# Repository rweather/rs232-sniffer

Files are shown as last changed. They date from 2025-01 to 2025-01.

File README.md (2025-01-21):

RS-232 Sniffer Box
==================

This repository contains schematics, a PCB layout, and 3D-printable box
for a "RS-232 Sniffer" that my friend Chris asked me to design in 2019.

Chris needed a way to sniff the traffic between two serial devices,
and to get a visual indication as to which signals were active.

A little bit of mucking around in [KiCad](https://www.kicad.org/) and
[OpenSCAD](https://openscad.org/) and I had a design.  Chris later
improved on my original 3D-printable box design.

Multiple copies of the box have been made and have seen heavy use at
our workplace for monitoring serial communications; particularly for
SCADA systems.

The boxes have also proven useful to check if serial ports are working
at all, and to track down problems with RTS/CTS handshaking and the like.

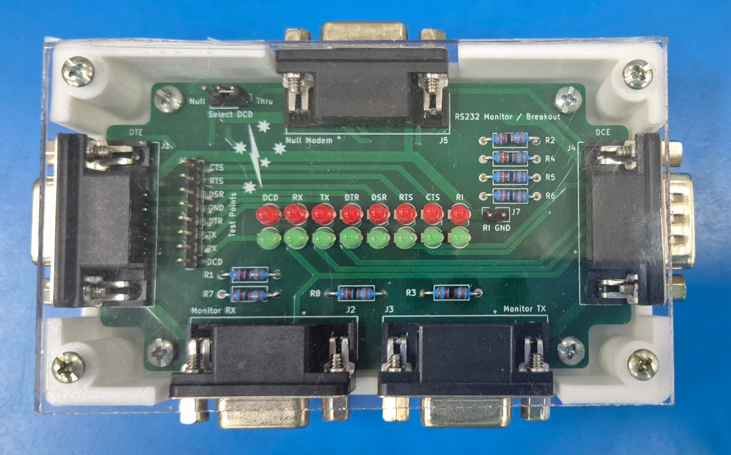
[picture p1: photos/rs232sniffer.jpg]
RS-232 Sniffer Box


## Capabilities

* Pass-through from one end of the box to the other for the main
serial communications path.
* Two extra serial ports for monitoring the RX and TX sides of the
communications.  Any bytes that are sent on that side are also sent
to the "sniffer" ports, for monitoring on a connected PC using a
terminal program like [PuTTY](https://www.putty.org/).
* Optional null modem connection to cross-over RX and TX.
* Red and green LED's to indicate which RS-232 lines have a high or
low signal on them.
* Probe points to monitor the RS-232 signals on an oscilloscope.

Note that this is a sniffer rather than a breakout box, so it isn't
possible to reroute the signals from one end to the other.  All serial
ports are assumed to use the standard IBM RS-232 DB9 arrangement.

## Schematics

The KiCad schematics are in the `schematics/RS232Sniffer` directory.
The PDF version can be found [here](schematics/RS232Sniffer/PDF/RS232Sniffer.pdf).

## Gerber Files

The Gerber files can be found in the `schematics/RS232Sniffer/Gerber` directory.

## Parts List

<table border="1">
<tr><td><b>Part</b></td><td><b>Quantity</b></td><td><b>Designators</b></td></td></tr>
<tr><td>PCB</td><td>1</td><td>N/A</td></tr>
<tr><td>3mm Red LED</td><td>8</td><td>D1,D3,D5,D7,D9,D11,D13,D15 (top row)</td></tr>
<tr><td>3mm Green LED</td><td>8</td><td>D2,D4,D6,D8,D10,D12,D14,D16 (bottom row)</td></tr>
<tr><td>DB9 female connector</td><td>4</td><td>J1,J2,J3,J5</td></tr>
<tr><td>DB9 male connector</td><td>1</td><td>J4</td></tr>
<tr><td>8-pin 2.54mm terminal header or socket</td><td>1</td><td>J6</td></tr>
<tr><td>2-pin 2.54mm terminal header or socket</td><td>1</td><td>J7</td></tr>
<tr><td>1.2k Resistor, either 1/4W or 1/2W</td><td>8</td><td>R1,R2,R3,R4,R5,R6,R7,R8</td></tr>
<tr><td>SPDT slide switch or 3-pin terminal header, 2.54mm pitch</td><td>1</td><td>SW1 (normally set to the "Thru" position)</td></tr>
</table>

Jaycar has the DB9 connectors as part codes PS-0806 (female) and
PP-0803 (male).

## 3D-Printable Box

* [STL file for the box](box/RS232SnifferBox.stl)
* [OpenSCAD file for the box](box/RS232SnifferBox.scad)

Use metal sheet screws to affix the PCB to the bottom of the box.
The mounting holes may need to be drilled out a little depending upon
the type of screws you are using.

A lid cut from transparent acrylic sheet completes the look.

## License

<p xmlns:cc="http://creativecommons.org/ns#" xmlns:dct="http://purl.org/dc/terms/"><span property="dct:title">RS-232 Sniffer</span> by <span property="cc:attributionName">Rhys Weatherley</span> is licensed under <a href="http://creativecommons.org/licenses/by-nc-sa/4.0/?ref=chooser-v1" target="_blank" rel="license noopener noreferrer" style="display:inline-block;">Attribution-NonCommercial-ShareAlike 4.0 International</a></p>

## Contact

For more information on this project, or to suggest improvements,
please contact the author Rhys Weatherley via
[email](mailto:rhys.weatherley@gmail.com).

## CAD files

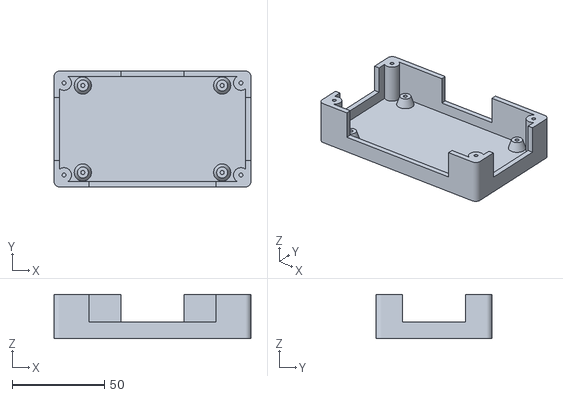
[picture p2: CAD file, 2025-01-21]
box/RS232SnifferBox.stl
107.0 x 63.0 x 24.0

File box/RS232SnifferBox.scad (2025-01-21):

$fn = 200;

// Diameter of screw holes in the mounting posts.  Intended for 4G metal screws.
holedia = 2.2;

// Set 'cutaway' to true to cut away the side of the box to see the detail.
//cutaway = true;
cutaway = false;

// Set this to true to show the PCB inside the box.
//showpcb = true;
showpcb = false;

module RS232Connector() {
    translate([0, 0, 7]) cube([31, 17, 12], center=true);
}

module PCB() {
    difference() {
        cube([99.06, 54.61, 2], center=true);
        translate([45.5, 23.25, 0]) cube([8.2, 8.2, 4], center=true);
        translate([45.5, -23.25, 0]) cube([8.2, 8.2, 4], center=true);
        translate([-45.5, 23.25, 0]) cube([8.2, 8.2, 4], center=true);
        translate([-45.5, -23.25, 0]) cube([8.2, 8.2, 4], center=true);
        translate([37.845, 23.62, 0]) cylinder(h=4, d=3, center=true);
        translate([37.845, -23.62, 0]) cylinder(h=4, d=3, center=true);
        translate([-37.845, 23.62, 0]) cylinder(h=4, d=3, center=true);
        translate([-37.845, -23.62, 0]) cylinder(h=4, d=3, center=true);
    }
    translate([0, 26, 0]) RS232Connector();
    translate([17.5, -26, 0]) rotate([0, 0, 180]) RS232Connector();
    translate([-17.5, -26, 0]) rotate([0, 0, 180]) RS232Connector();
    translate([-48, 0, 0]) rotate([0, 0, 90]) RS232Connector();
    translate([48, 0, 0]) rotate([0, 0, -90]) RS232Connector();
}

module BoxShape(adjust) {
    linear_extrude(height=24) {
        hull() {
            translate([50.5 - adjust, 28.5 - adjust]) circle(3);
            translate([50.5 - adjust, -28.5 + adjust]) circle(3);
            translate([-50.5 + adjust, 28.5 - adjust]) circle(3);
            translate([-50.5 + adjust, -28.5 + adjust]) circle(3);
        }
    }
}

module OuterHull() {
    difference() {
        BoxShape(0);
        translate([0, 0, 3]) BoxShape(3);
        translate([0, 30, 17]) cube([34, 5, 16], center=true);
        translate([0, -30, 17]) cube([69, 5, 16], center=true);
        translate([-52, 0, 17]) rotate([0, 0, 90]) cube([34, 5, 16], center=true);
        translate([52, 0, 17]) rotate([0, 0, 90]) cube([34, 5, 16], center=true);
        if (cutaway)
            translate([0, -30, 0]) cube([110, 20, 50], center=true);
    }
}

module MountingPost() {
    difference() {
        //cylinder(h=6, d=6);
        cylinder(h=6, r1=5, r2=3);
        translate([0, 0, -1.5]) cylinder(h=20, d=holedia);
    }
}

module CornerPost() {
    difference() {
        cylinder(h=22, d=8);
        translate([0, 0, 3]) cylinder(h=20, d=holedia);
    }
}

module Box() {
    OuterHull();
    translate([48, 25, 2]) CornerPost();
    translate([48, -25, 2]) CornerPost();
    translate([-48, 25, 2]) CornerPost();
    translate([-48, -25, 2]) CornerPost();
    translate([37.845, 23.62, 2]) MountingPost();
    translate([37.845, -23.62, 2]) MountingPost();
    translate([-37.845, 23.62, 2]) MountingPost();
    translate([-37.845, -23.62, 2]) MountingPost();
}

if (showpcb)
    color([0, 0.5, 0, 1]) translate([0, 0, 9]) PCB();
Box();

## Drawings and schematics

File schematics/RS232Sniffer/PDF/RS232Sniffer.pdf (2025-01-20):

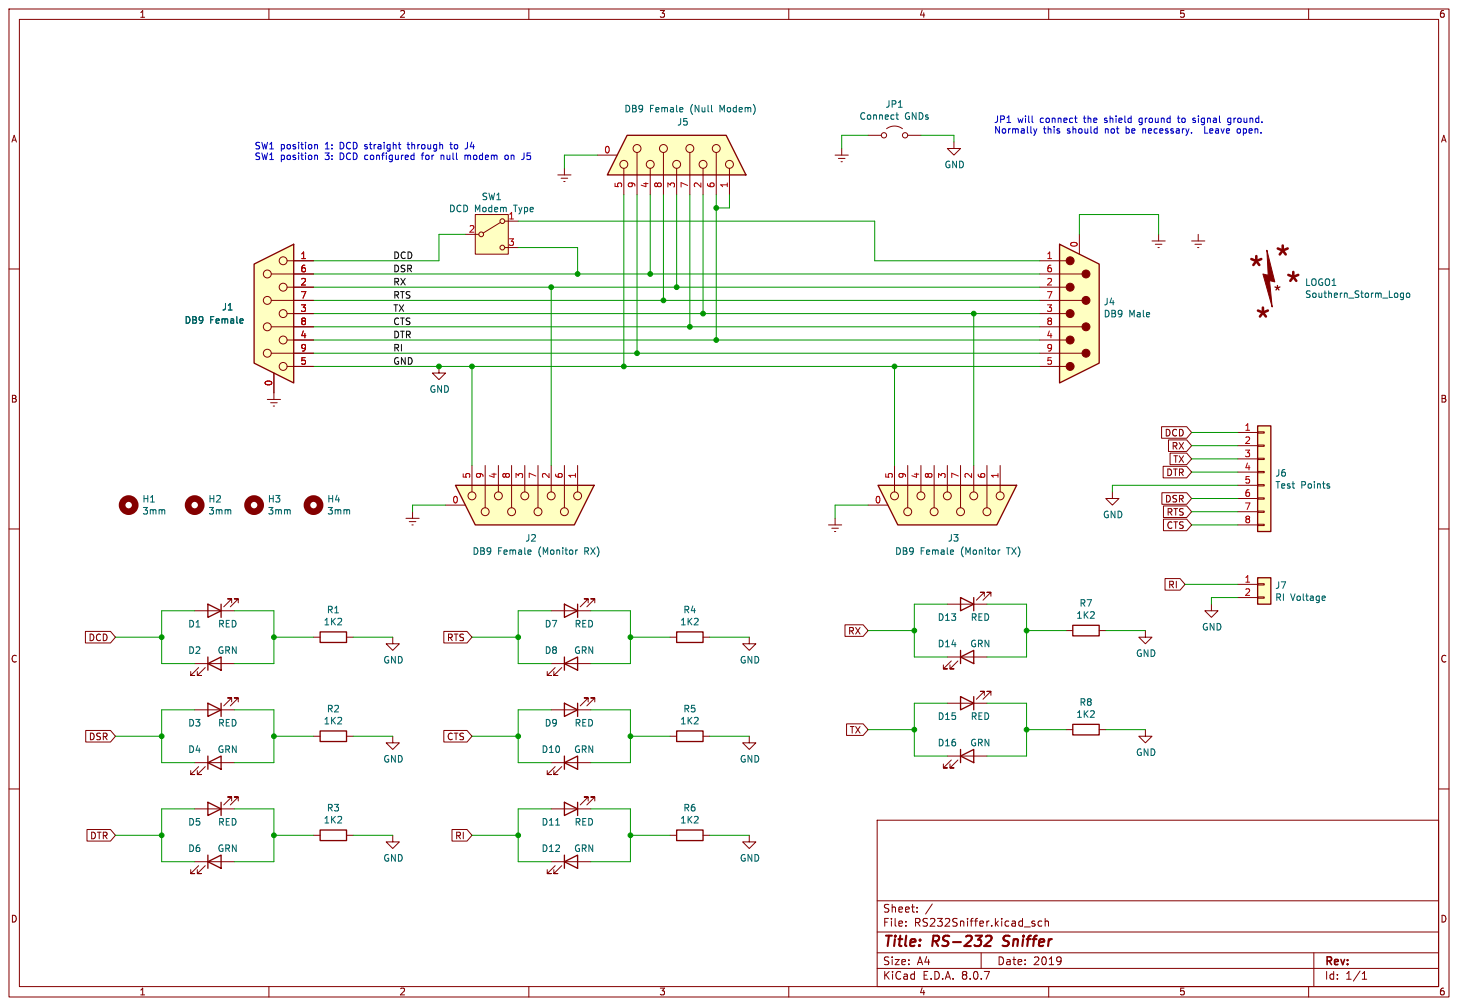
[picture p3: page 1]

JP1 will connect the shield ground to signal ground.

3 SW1 DCD Modem Type GND

DCD
RTS CTS RI RXDSR

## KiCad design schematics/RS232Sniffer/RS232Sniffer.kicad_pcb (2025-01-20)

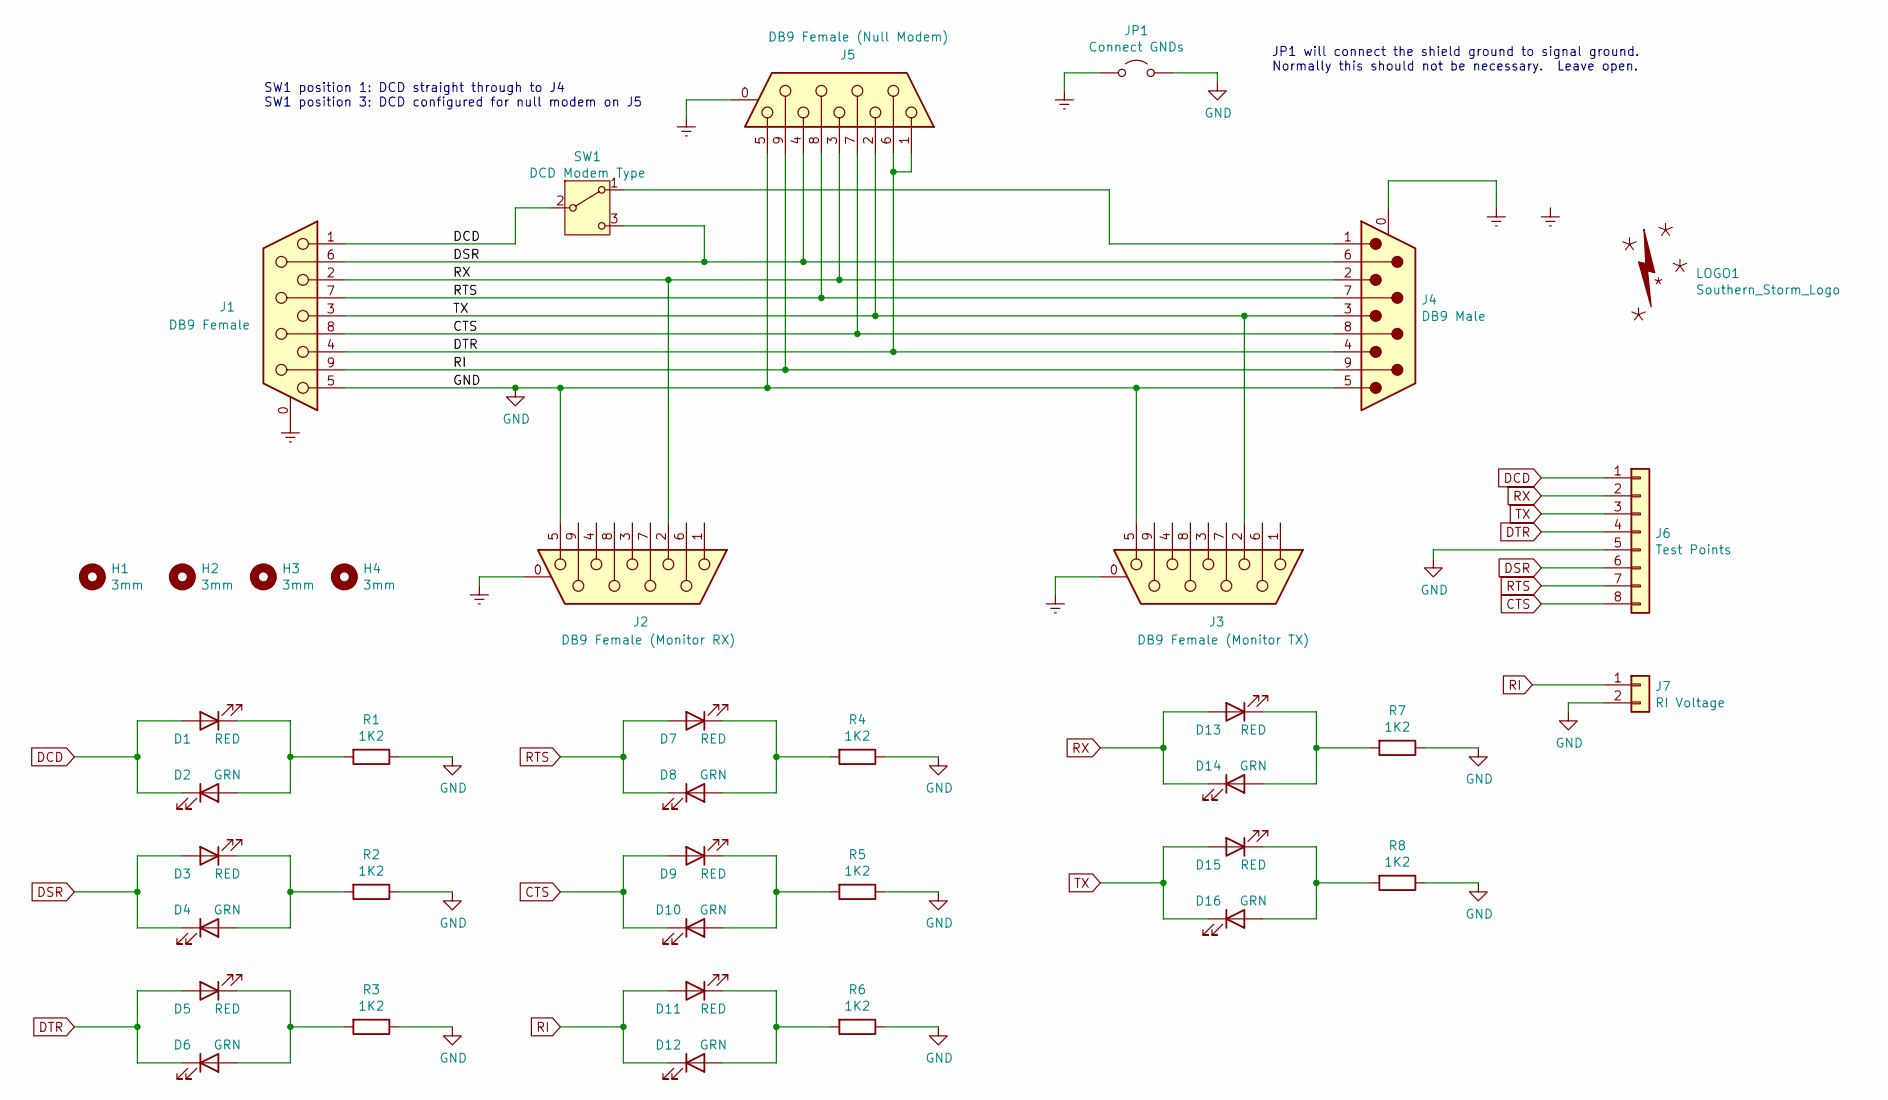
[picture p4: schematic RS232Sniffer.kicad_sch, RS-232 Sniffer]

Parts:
D1, D3, D5, D7, D9, D11, D13, D15: RED; LED_D3.0mm
D2, D4, D6, D8, D10, D12, D14, D16: GRN; LED_D3.0mm
H1, H2, H3, H4: 3mm; MountingHole_3mm
J1: DB9 Female; DSUB-9_Female_Horizontal_P2.77x2.84mm_EdgePinOffset4.94mm_H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
J2: DB9 Female (Monitor RX); DSUB-9_Female_Horizontal_P2.77x2.84mm_EdgePinOffset4.94mm_H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
J3: DB9 Female (Monitor TX); DSUB-9_Female_Horizontal_P2.77x2.84mm_EdgePinOffset4.94mm_H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
J4: DB9 Male; DSUB-9_Male_Horizontal_P2.77x2.84mm_EdgePinOffset4.94mm_Hou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
J5: DB9 Female (Null Modem); DSUB-9_Female_Horizontal_P2.77x2.84mm_EdgePinOffset4.94mm_H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
J6: Test Points; PinSocket_1x08_P2.54mm_Vertical
J7: RI Voltage; PinSocket_1x02_P2.54mm_Vertical
JP1: Connect GNDs; SolderJumper-2_P1.3mm_Open_RoundedPad1.0x1.5mm
LOGO1: Southern_Storm_Logo; Logo_Southern_Storm
R1, R2, R3, R4, R5, R6, R7, R8: 1K2; R_Axial_DIN0207_L6.3mm_D2.5mm_P10.16mm_Horizontal
SW1: DCD Modem Type; PinHeader_1x03_P2.54mm_Vertical

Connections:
CTS: D9.2 (A), D10.1 (K), J1.8, J4.8, J5.7, J6.8
DCD: D1.2 (A), D2.1 (K), J1.1, J6.1, SW1.2 (B)
DSR: D3.2 (A), D4.1 (K), J1.6, J4.6, J5.4, J6.6, SW1.3 (C)
DTR: D5.2 (A), D6.1 (K), J1.4, J4.4, J5.1, J5.6, J6.4
Earth: J1.0 (PAD), J2.0 (PAD), J3.0 (PAD), J4.0 (PAD), J5.0 (PAD), JP1.1 (A)
GND: J1.5, J2.5, J3.5, J4.5, J5.5, J6.5, J7.2, JP1.2 (B), R1.1, R2.1, R3.1, R4.1, R5.1, R6.1, R7.1, R8.1
unnamed: D1.1 (K), D2.2 (A), R1.2
unnamed: D3.1 (K), D4.2 (A), R2.2
unnamed: D5.1 (K), D6.2 (A), R3.2
unnamed: D7.1 (K), D8.2 (A), R4.2
unnamed: D9.1 (K), D10.2 (A), R5.2
unnamed: D11.1 (K), D12.2 (A), R6.2
unnamed: D13.1 (K), D14.2 (A), R7.2
unnamed: D15.1 (K), D16.2 (A), R8.2
unnamed: J4.1, SW1.1 (A)
RI: D11.2 (A), D12.1 (K), J1.9, J4.9, J5.9, J7.1
RTS: D7.2 (A), D8.1 (K), J1.7, J4.7, J5.8, J6.7
RX: D13.2 (A), D14.1 (K), J1.2, J2.2, J4.2, J5.3, J6.2
TX: D15.2 (A), D16.1 (K), J1.3, J3.2, J4.3, J5.2, J6.3

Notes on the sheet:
JP1 will connect the shield ground to signal ground. Normally this should not be necessary. Leave open.
SW1 position 1: DCD straight through to J4 SW1 position 3: DCD configured for null modem on J5

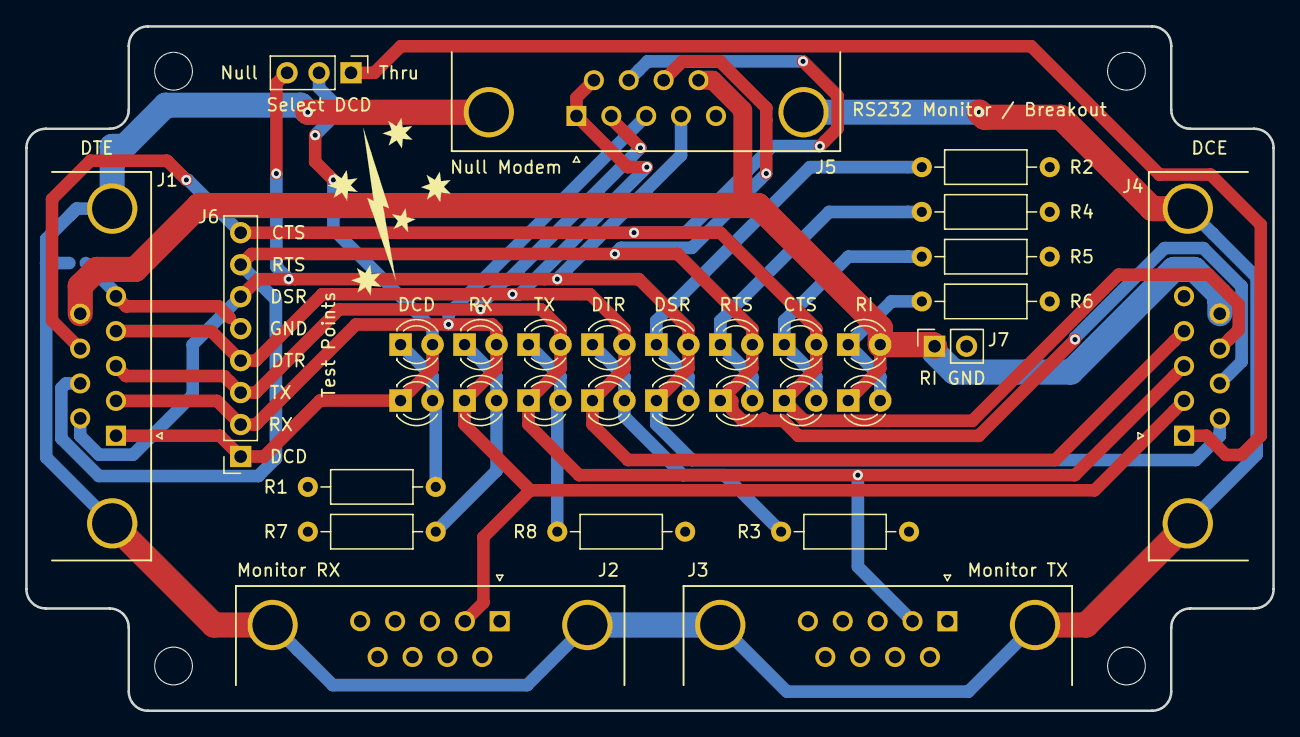
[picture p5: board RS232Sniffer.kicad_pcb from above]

Board: 2 copper layers, 99.1 x 54.4 mm, 38 parts (1 on the bottom side), 19 nets.

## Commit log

2025-01-20 Check in the schematics and Gerber files
    [RS232Sniffer-B.Cu.gbl, RS232Sniffer-B.Mask.gbs, RS232Sniffer-B.Paste.gbp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]
2025-01-21 Add the 3D-printable box files
    [RS232SnifferBox.scad, RS232SnifferBox.stl]
